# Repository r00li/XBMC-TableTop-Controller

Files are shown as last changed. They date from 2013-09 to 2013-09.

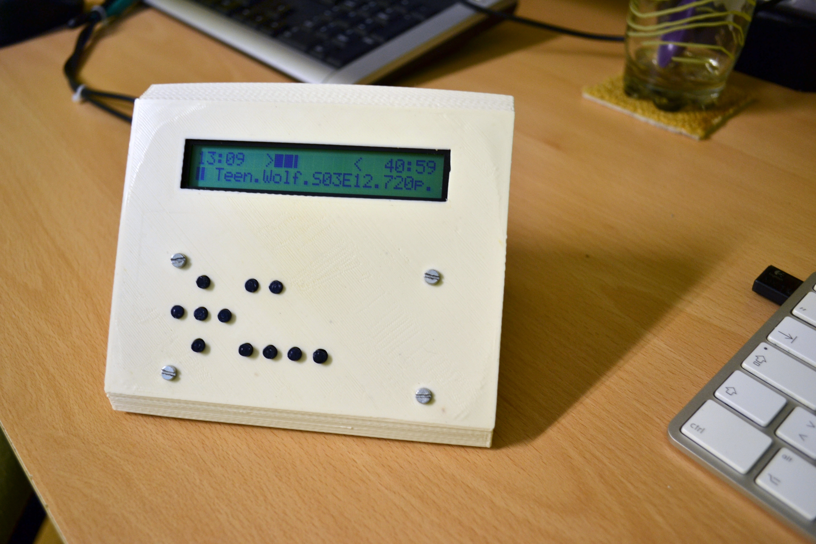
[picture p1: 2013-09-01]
Case design/DSC_0210.JPG

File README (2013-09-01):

XBMC TableTop Controller 
version 1.0
Copyright 2013 Andrej Rolih
http://www.r00li.com

About:
This is a simple table-top multimedia controller. It is design to interface with the XBMC media player. It uses a 24x2 LCD character display to show current playback information and offers 11 buttons for playback control.

Building instructions:
You will need to make a PCB - I recommend making it at home with the toner transfer method. After you have the PCB and you have mounted all the components (you should upload the sketch to the ATMega chip before - use a DIP socket so you can easily remove it from the PCB) (parts list is in the PCB folder) you'll need to make a case. A case design is provided. I included the original sketchup file and the stl files that should be ready for 3D printing. You'll need 4 M3 screws and 4 M3 spacers (their length depends on the components used - cut them to minimal length) to mount the PCB in place. 

Source code for both Java application and Arduino controller is provided here. PCB schematic is also provided. PCB was created using diptrace - diptrace is free program available here: http://www.diptrace.com

Software: 
Software currently includes a simple tray-GUI that enables you to set the connection settings for the controller. Controller is usually connected to the computer where the XBMC is running so localhost should be used. You can also control a network player if you want. The bottom four buttons currently don't have a function pre-programmed. You'll need to add a function yourself if you want to use them. Check out the XBMC JSON API for the list of supported commands.

Dependencies:
You'll need two Java libraries to compile this project:
JsonRPC2 Base and JsonRPC2 Client: http://software.dzhuvinov.com/json-rpc-2.0-client.html
JSSC: http://code.google.com/p/java-simple-serial-connector/

The required .jar files are included in the /dist/lib directory so you can use those.

Contact:
If you have any questions about this project, you can contact me at: roli.r00li@gmail.com

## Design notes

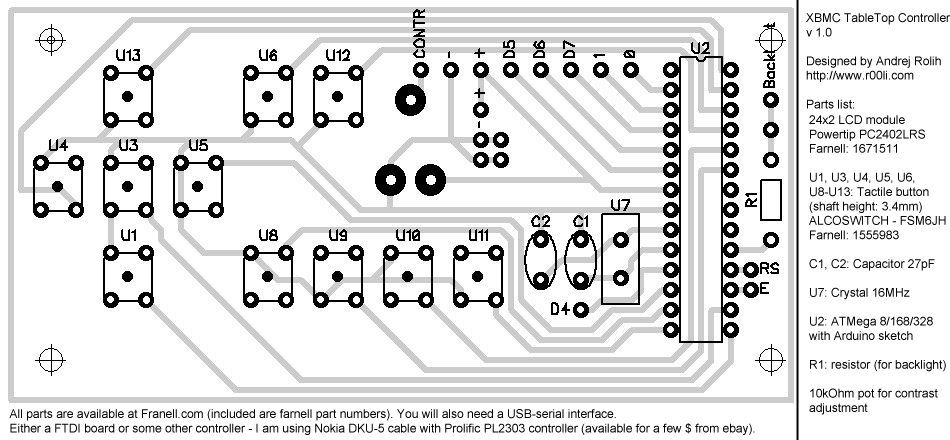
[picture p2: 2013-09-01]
PCB/XBMC_table_v1.png

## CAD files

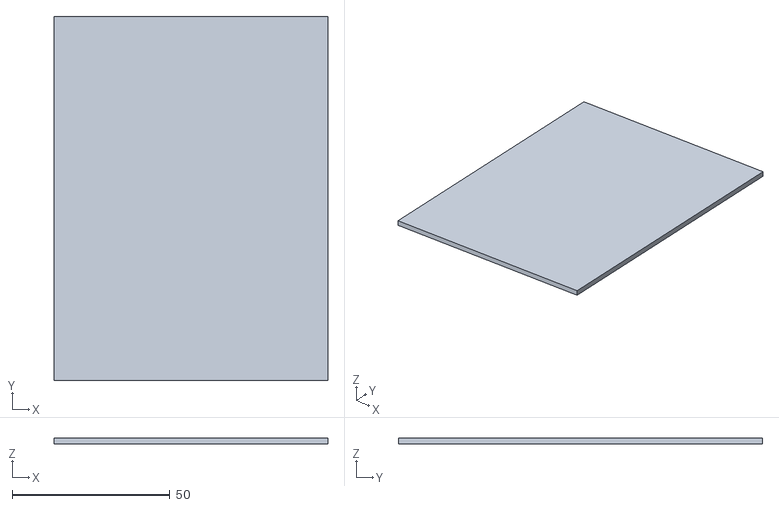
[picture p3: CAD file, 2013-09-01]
Case design/cover.stl
86.7 x 115.2 x 2.00

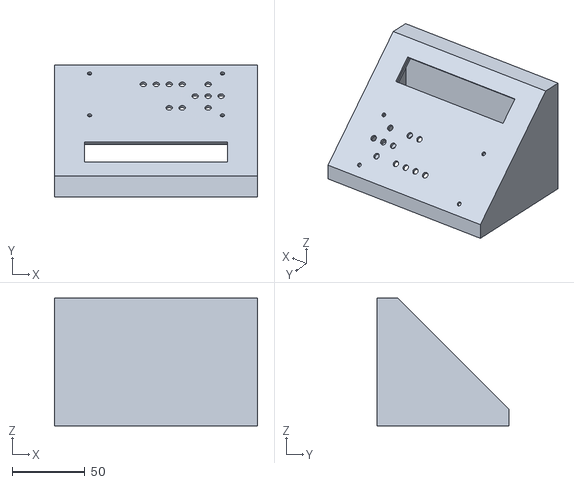
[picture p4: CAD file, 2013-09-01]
Case design/case.stl
139.2 x 90.7 x 87.7

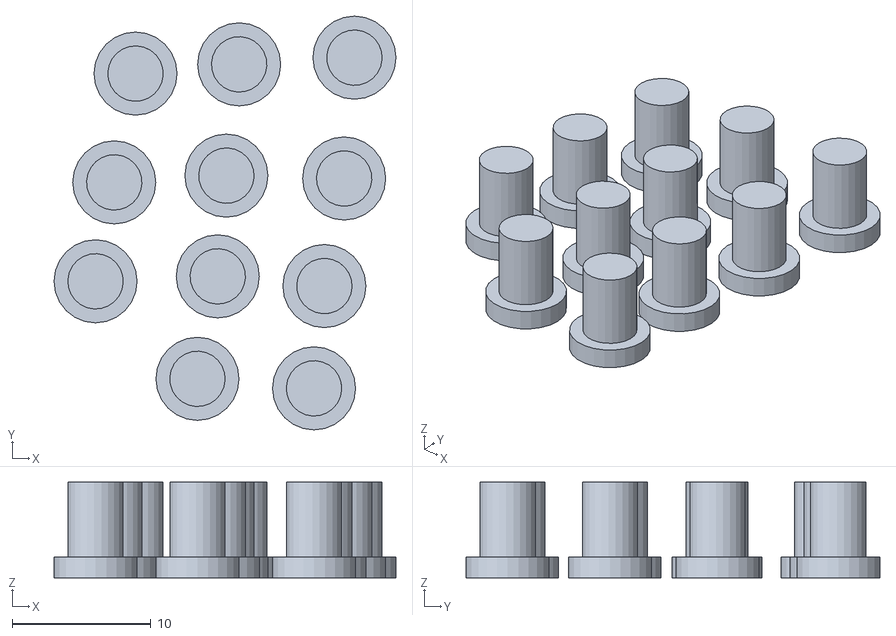
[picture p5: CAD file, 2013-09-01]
Case design/buttons.stl
24.7 x 29.9 x 6.90

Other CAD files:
Case design/XBMCTableTop.skp

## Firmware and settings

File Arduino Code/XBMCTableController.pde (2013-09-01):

/*
 * XBMC TableTop Controller version 1.0
 * http://www.r00li.com
 * Copyright 2013 Andrej Rolih
 * Licensed under GPLv3 - see LICENSE.txt
 * 
 * Uses standard Arduino libraries - tested with Arduino 0018
 * Look at the PCB file for hardware information.
 */



// include the library code:
#include <LiquidCrystal.h>

// initialize the library with the numbers of the interface pins
LiquidCrystal lcd(12, 11, 5, 4, 3, 2);

byte c0[8] = {
  B00000,
  B00000,
  B00000,
  B00000,
  B00000,
  B00000,
  B00000,
};

byte c1[8] = {
  B10000,
  B10000,
  B10000,
  B10000,
  B10000,
  B10000,
  B10000,
};

byte c2[8] = {
  B11000,
  B11000,
  B11000,
  B11000,
  B11000,
  B11000,
  B11000,
};

byte c3[8] = {
  B11100,
  B11100,
  B11100,
  B11100,
  B11100,
  B11100,
  B11100,
};

byte c4[8] = {
  B11110,
  B11110,
  B11110,
  B11110,
  B11110,
  B11110,
  B11110,
};

byte c5[8] = {
  B11111,
  B11111,
  B11111,
  B11111,
  B11111,
  B11111,
  B11111,
};

byte play[8] = {
  B10000,
  B11000,
  B11100,
  B11110,
  B11100,
  B11000,
  B10000,
};

byte pause[8] = {
  B11011,
  B11011,
  B11011,
  B11011,
  B11011,
  B11011,
  B11011,
};


char buff[26];
byte buff_pointer = 0;

char miniBuff[4];

long lastmessage = 0;



void setup() {
  // set up the LCD's number of rows and columns: 
  lcd.begin(24, 2);
  
  lcd.createChar(7, play);
  lcd.createChar(0, c0);
  lcd.createChar(1, c1);
  lcd.createChar(2, c2);
  lcd.createChar(3, c3);
  lcd.createChar(4, c4);
  lcd.createChar(5, c5);
  lcd.createChar(6, pause);

  pinMode(13,OUTPUT);
  digitalWrite(13, LOW);
  
  pinMode(6, INPUT);
  digitalWrite(6, HIGH);
  pinMode(7, INPUT);
  digitalWrite(7, HIGH);
  pinMode(8, INPUT);
  digitalWrite(8, HIGH);
  pinMode(9, INPUT);
  digitalWrite(9, HIGH);
  pinMode(10, INPUT);
  digitalWrite(10, HIGH);
  pinMode(14, INPUT);
  digitalWrite(14, HIGH);
  pinMode(15, INPUT);
  digitalWrite(15, HIGH);
  pinMode(16, INPUT);
  digitalWrite(16, HIGH);
  pinMode(17, INPUT);
  digitalWrite(17, HIGH);
  pinMode(18, INPUT);
  digitalWrite(18, HIGH);
  pinMode(19, INPUT);
  digitalWrite(19, HIGH);
  
  Serial.begin(9600);
  
  lcd.clear();
  lcd.print("XBMC controller v1.0");
  lcd.setCursor(0,1);
  lcd.print("Not plugged in");
}

void messageReceived() {
  if (buff_pointer >= 1) {
    
    if (buff[0] == 'L') {
      digitalWrite(13, HIGH);
      lcd.setCursor(0, 0);
      int pos = 1;
      while(pos < buff_pointer) {
        lcd.print(buff[pos]);
        pos++;
      }
    }
    else if (buff[0] == 'R') {
      lcd.setCursor(16, 0);
      int pos = 1;
      while(pos < buff_pointer) {
        lcd.print(buff[pos]);
        pos++;
      }
    }
    else if (buff[0] == 'P') {
      
      miniBuff[0] = buff[1];
      miniBuff[1] = buff[2];
      miniBuff[2] = '\0';
      
      int percentage = atoi(miniBuff);
      int prctg = map(percentage, 0, 99, 0, 40);
      
      lcd.setCursor(8,0);
      lcd.print("        ");
      lcd.setCursor(8,0);
      for (int i = 0; i < prctg/5; i++)
        lcd.write(byte(5));
        
      lcd.write(byte(prctg%5));
    }
    else if (buff[0] == 'S') {
      digitalWrite(13, HIGH);
      
      lcd.setCursor(0,1);
      if (buff[1] == '0')
        lcd.write(byte(6));
      else
        lcd.write(byte(7));
        
      int pos = 2;
      while(pos < buff_pointer) {
        lcd.print(buff[pos]);
        pos++;
      }
    }
    else if (buff[0] == 'B') {
      digitalWrite(13, LOW);
      lcd.clear();
      int pos = 1;
      lcd.print("      XBMC OFFLINE");
      lcd.setCursor(0,1);
      while(pos < buff_pointer) {
        lcd.print(buff[pos]);
        pos++;
      }
    }
  }
}

void loop() {
  
    while (Serial.available() > 0) {
    buff[buff_pointer] = Serial.read();
    
    if (buff[buff_pointer] == '\0') {
      lastmessage = millis();
      messageReceived();
      buff_pointer=0;
    }
    else {
      buff_pointer++;
    }
  }
  
  if (digitalRead(6) == LOW) {
    Serial.print("B3"); //gumb pritisnjen
    Serial.print('\0');
    delay(270);
  }
  if (digitalRead(7) == LOW) {
    Serial.print("B8"); //gumb pritisnjen
    Serial.print('\0');
    delay(270);
  }
  if (digitalRead(8) == LOW) {
    Serial.print("B11"); //gumb pritisnjen
    Serial.print('\0');
    delay(270);
  }
  if (digitalRead(9) == LOW) {
    Serial.print("B2"); //gumb pritisnjen
    Serial.print('\0');
    delay(270);
  }
  if (digitalRead(10) == LOW) {
    Serial.print("B5"); //gumb pritisnjen
    Serial.print('\0');
    delay(270);
  }
  if (digitalRead(14) == LOW) {
    Serial.print("B9"); //gumb pritisnjen
    Serial.print('\0');
    delay(250);
  }
  if (digitalRead(15) == LOW) {
    Serial.print("B10"); //gumb pritisnjen
    Serial.print('\0');
    delay(270);
  }
  if (digitalRead(16) == LOW) {
    Serial.print("B7"); //gumb pritisnjen
    Serial.print('\0');
    delay(270);
  }
  if (digitalRead(17) == LOW) {
    Serial.print("B6"); //gumb pritisnjen
    Serial.print('\0');
    delay(270);
  }
  if (digitalRead(18) == LOW) {
    Serial.print("B4"); //gumb pritisnjen
    Serial.print('\0');
    delay(270);
  }
  if (digitalRead(19) == LOW) {
    Serial.print("B1"); //gumb pritisnjen
    Serial.print('\0');
    delay(270);
  }

  if (millis() - lastmessage > 30000) {
    digitalWrite(13, LOW);
    lcd.setCursor(0,0);
    lcd.print("XBMC controller v1.0    ");
    lcd.setCursor(0,1);
    lcd.print("Not plugged in          ");
  }
  
  // set the cursor to column 0, line 1
  // (note: line 1 is the second row, since counting begins with 0):
  // print the number of seconds since reset:

}
